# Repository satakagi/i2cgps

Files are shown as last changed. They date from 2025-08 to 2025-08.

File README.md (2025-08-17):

# I2CGPS

これは一般的なGPSレシーバ (GY-NEO6MV2など、UART 9600bpsでNMEA0183形式のデータを出力する。3.3Vでも動くもの) をI2Cインターフェースで使用できるようにするものです。メインコンピューターのUARTに余裕がないときに便利かもしれません。Arduino Pro Mini 3.3V (8MHz)でI2Cに変換しています。GY-NEO6MV2+Arduino Pro Mini 3.3V互換ボード+CHIRIMEN PiZero環境で動作確認をしました。

https://github.com/ckuethe/i2cgps をフォークして開発しました。そのため、i2cのインターフェース仕様はフォーク元に準じます。
ただ、私のArduino環境ではオリジナルのソース(.ino)はうまく動かなかったので、GPSライブラリの変更を伴う作り直しをしています。

原作者さんはATTiny85への移行を目指したようですが未達、この実装もArduino(ATMega248)用です。

また、以下を追加しています。
* [chirimen](https://www.chirimen.org)用のドライバとサンプル：[chirimen](./chirimen/)ディレクトリ
* 実体配線図：[hardware](./hardware)
* 未検証ですが・・KiCadのプリント基板設計図：[hardware/KiCad/](./hardware/KiCad/)

## 準備するもの
* GPSレシーバ([GY-NEO6MV2](https://electronicwork.shop/items/625c1ca99fe3d707d725cbe1)で確認しています)
* Arduiono Pro Mini 3.3V (8MHz) （もしくはその互換ボード）：この配線図通りで動かすには3.3V版が必要です ([互換ボードは数百円](https://electronicwork.shop/items/64e2182be37f74003b45e342)で購入できると思います)
* Arduiono Pro Miniにファームウェア(スケッチ)を書き込むための環境(ハードとしてはFTDI USBシリアル変換アダプター([数百円](https://electronicwork.shop/items/63412a95c15c5a192180482f)で買えると思います)が必要です)
* [Chirimen Pi Zero 環境](https://tutorial.chirimen.org/pizero/)

## 動かし方
* ファームウェアの書き込み：Arduino Pro Mini 3.3V(もしくはその互換ボード)にUSB-シリアル(専用のものが安価に流通しています)に、ArduinoIDEで[i2cgps.ino](./i2cgps.ino)を書き込みます
* 実体配線図のようにつなぎます
* GPSレシーバが測位できていなくても、空のデータが送信されてくるため、Arduino側のLEDは点滅するはずです（点滅していないときはどこかに問題がある）
* 測位できるとGPSレシーバ側のLEDも点滅します(GY-NEO6MV2の場合)
* chirimen piZero環境で[サンプルコード(ドライバ付き)](./chirimen/main.js)を実行すると、データが出力されます

## 実体配線図
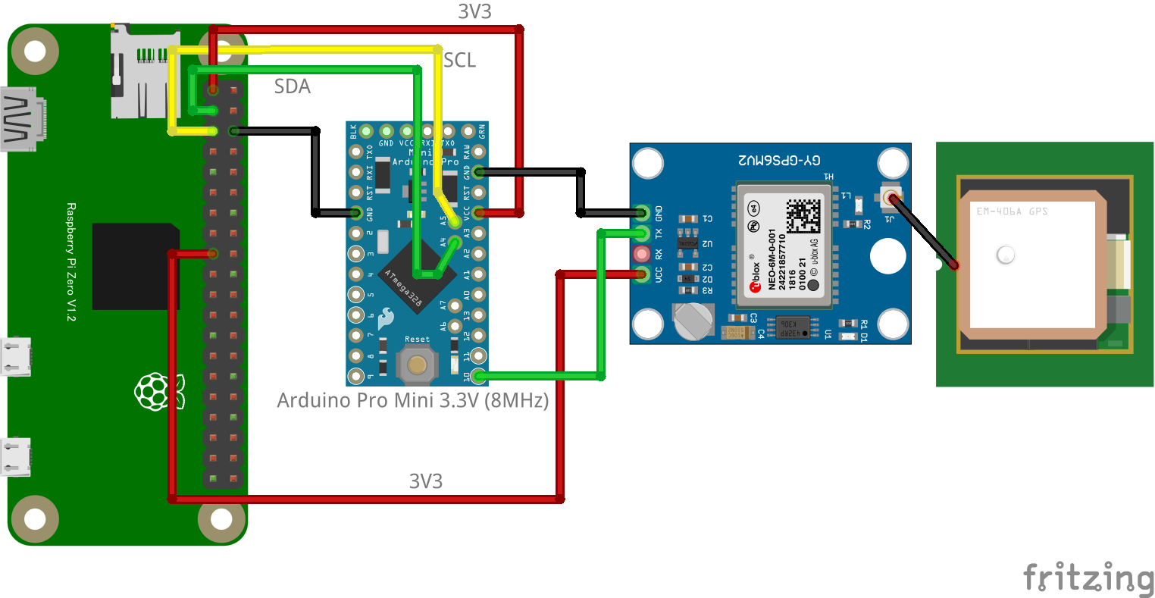
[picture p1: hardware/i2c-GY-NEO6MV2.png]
実体配線図


## ライセンス
ライセンスは原作者さんが明示していないので・・・　[The TAPR Open Hardware License](https://tapr.org/the-tapr-open-hardware-license/)を提示しておきます。

---

## 以下は原作者 (ckuetheさん)の作成されたREADMEです。

From time to time you want to attach a GPS to a microcontroller and
you're already using all the serial ports. Luckily we have another bus:
I2C. You could call it a kind of a controller-area-network, given that
there are master and slave devices, each of which has a unique address.

Unfortunately there are very few commercial
[I2C GPS](https://www.sparkfun.com/products/14414) receivers and they
just do NMEA over I2C. There are
[other projects](http://www.technoblogy.com/show?1LJI) that do something similar, but with a higher part count. 

This particular implementation rather wastefully uses an ATmega, eg. an
Arduino Nano.

### TODO

* port this to attiny85, eg. digispark

### Other Links

* https://playground.arduino.cc/Code/USIi2c/
* https://github.com/rambo/TinyWire/tree/master/TinyWireS
* https://github.com/lucullusTheOnly/TinyWire
* https://github.com/adafruit/TinyWireM
* https://github.com/harbaum/I2C-Tiny-USB/tree/master/digispark
* https://digistump.com/board/index.php?topic=2831.0
* https://digistump.com/board/index.php?topic=1147.0
* https://digistump.com/wiki/digispark/tutorials/lcd

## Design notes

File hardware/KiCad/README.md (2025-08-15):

# I2CGPS専用基板
KiCadで専用基板をデザインしてみました。が、この基板は原案のみで製作していませんので未検証です。

## 回路図
Arduino Pro Miniをベースにしています
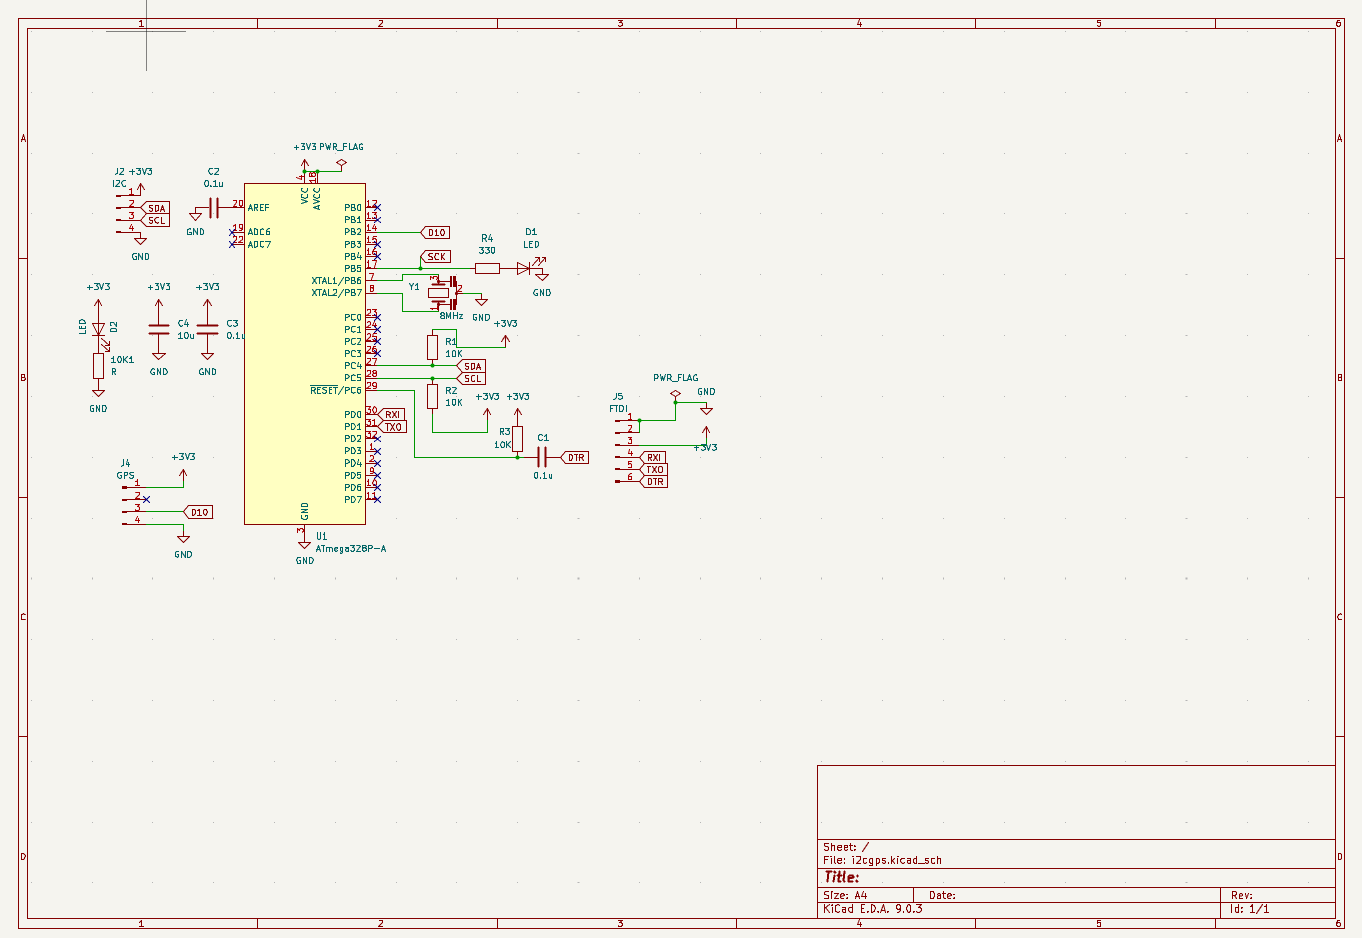
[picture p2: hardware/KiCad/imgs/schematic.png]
回路図


## PCBイメージ
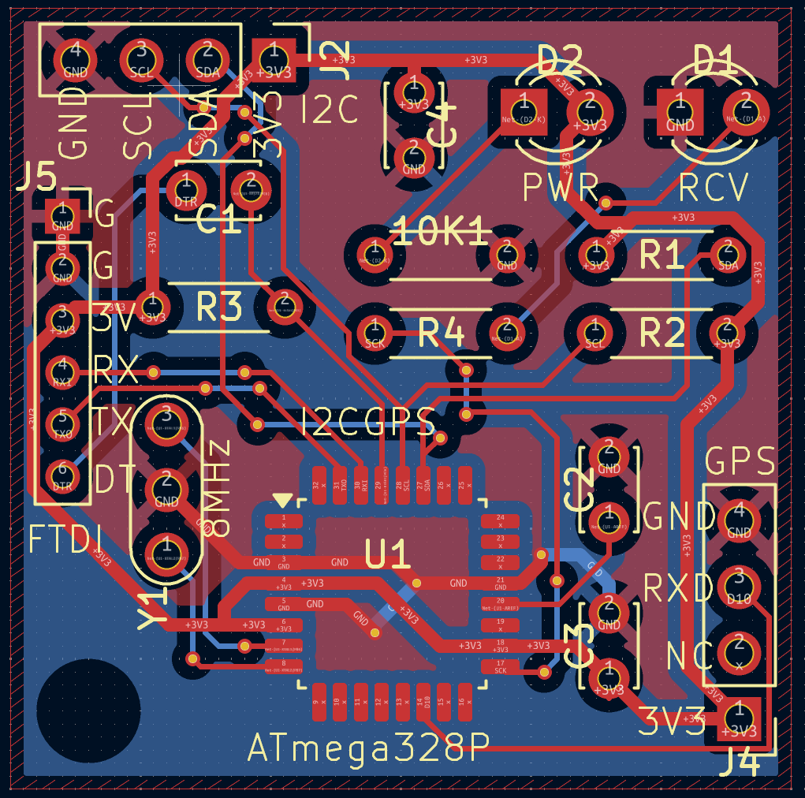
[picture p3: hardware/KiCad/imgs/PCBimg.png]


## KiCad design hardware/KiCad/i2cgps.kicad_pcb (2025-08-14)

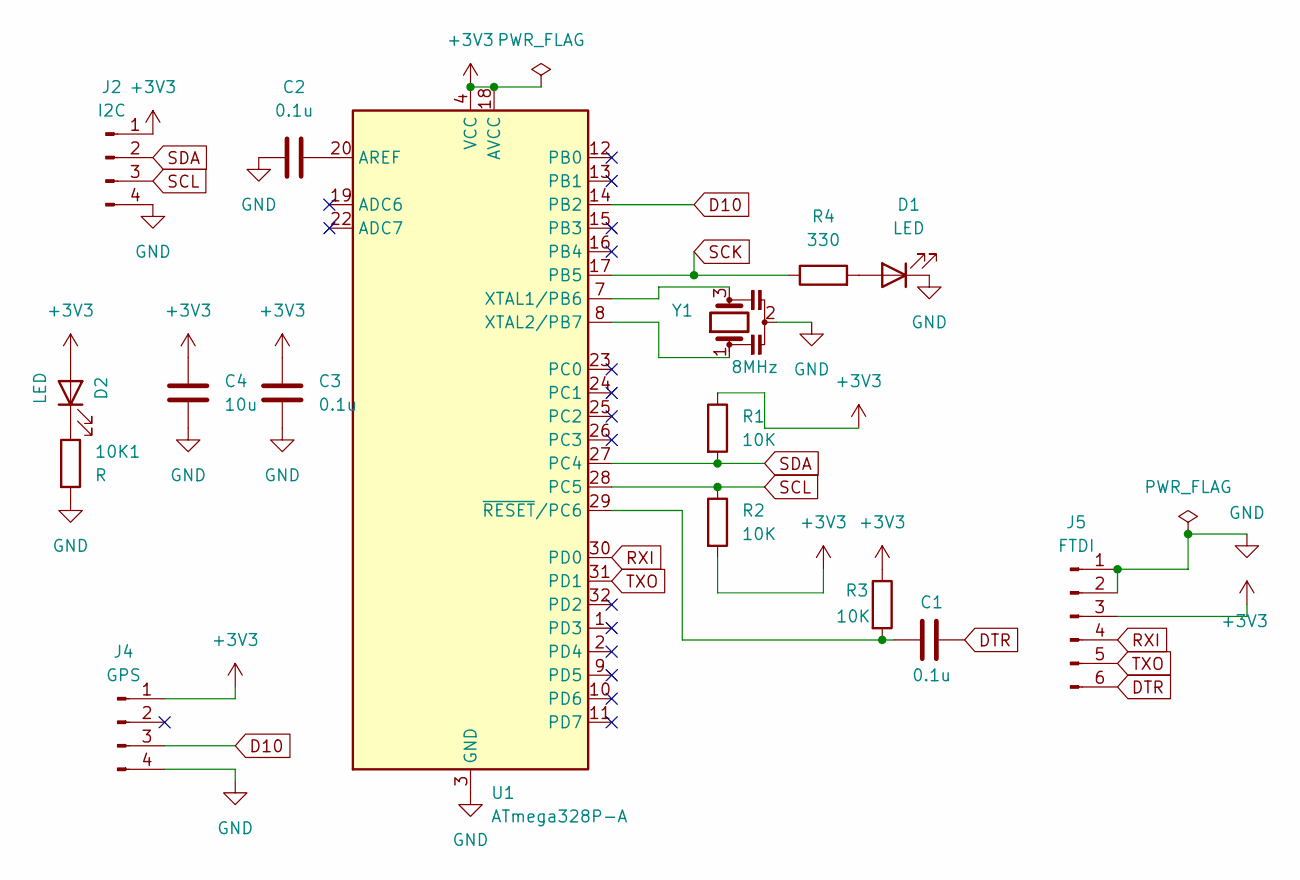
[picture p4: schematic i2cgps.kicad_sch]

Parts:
10K1: R; R_Axial_DIN0204_L3.6mm_D1.6mm_P5.08mm_Horizontal
C1, C2, C3: 0.1u; C_Disc_D3.0mm_W2.0mm_P2.50mm
C4: 10u; C_Disc_D3.0mm_W2.0mm_P2.50mm
D1, D2: LED; LED_D3.0mm
J2: I2C; PinHeader_1x04_P2.54mm_Vertical
J4: GPS; PinHeader_1x04_P2.54mm_Vertical
J5: FTDI; PinSocket_1x06_P2.00mm_Vertical
R1, R2, R3: 10K; R_Axial_DIN0204_L3.6mm_D1.6mm_P5.08mm_Horizontal
R4: 330; R_Axial_DIN0204_L3.6mm_D1.6mm_P5.08mm_Horizontal
U1: ATmega328P-A; TQFP-32_7x7mm_P0.8mm
Y1: 8MHz; Resonator_Murata_DSN6-3Pin_W7.0mm_H2.5mm

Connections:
+3V3: C3.1, C4.1, D2.2 (A), J2.1, J4.1, J5.3, R1.1, R2.2, R3.1, U1.4 (VCC), U1.6 (VCC), U1.18 (AVCC)
D10: J4.3, U1.14 (PB2)
DTR: C1.1, J5.6
GND: 10K1.2, C2.2, C3.2, C4.2, D1.1 (K), J2.4, J4.4, J5.1, J5.2, U1.3 (GND), U1.5 (GND), U1.21 (GND), Y1.2
unnamed: D1.2 (A), R4.2
unnamed: 10K1.1, D2.1 (K)
unnamed: C2.1, U1.20 (AREF)
unnamed: U1.7 (XTAL1/PB6), Y1.3
unnamed: U1.8 (XTAL2/PB7), Y1.1
unnamed: C1.2, R3.2, U1.29 (~RESET/PC6)
RXI: J5.4, U1.30 (PD0)
SCK: R4.1, U1.17 (PB5)
SCL: J2.3, R2.1, U1.28 (PC5)
SDA: J2.2, R1.2, U1.27 (PC4)
TXO: J5.5, U1.31 (PD1)

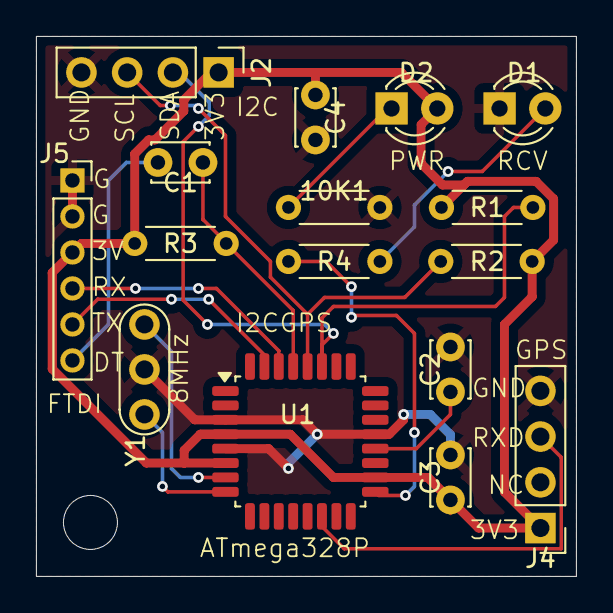
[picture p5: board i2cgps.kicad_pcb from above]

Board: 2 copper layers, 30.0 x 30.0 mm, 16 parts (0 on the bottom side), 15 nets.

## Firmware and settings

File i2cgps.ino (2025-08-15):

/*
 * Yet Another I2C GPS firmware with TinyGPSPlus
 *
 * TinyGPSPlusライブラリを使用してGPSデータを解析し、
 * I2C経由でデータを送信するファームウェアです。
 * NeoSWSerialでソフトウェアシリアル通信を行います。
 *
 * 【変更点】
 * ・使用ライブラリをNeoGPSからTinyGPSPlusに変更。(日付がおかしかった)
 * ・ライブラリのバージョン互換性のため、基本的な機能に絞って実装。
 * ・I2C送信時の緯度・経度データの計算方法を修正し、精度を向上。
 */

#include <Wire.h>
#include <WireData.h>
#include <NeoSWSerial.h>
#include <TinyGPSPlus.h> // TinyGPSPlusライブラリをインクルード

// GPSモジュールのボーレート
const long GPS_BAUD_RATE = 9600;

// PCのシリアルモニターのボーレート
const long PC_BAUD_RATE = 57600;

// I2Cアドレス
const int i2c_addr = 0x58;

// GPSモジュールのRXピンとTXピンを設定
NeoSWSerial gpsPort(10, 19); 

// TinyGPSPlusオブジェクトの宣言
TinyGPSPlus gps;

// I2Cで送信するデータ構造体
typedef struct fix {
  uint8_t fixlen;
  uint8_t status;
  uint16_t year;
  uint8_t month, day, hour, minute, second;
  int32_t lat, lon;
  int32_t alt;
  uint32_t speed;
} Fix_t;

// 送信するデータ構造体
static Fix_t i2c_fix;

// I2Cリクエストハンドラ
void i2c_position_request() {
  i2c_fix.fixlen = sizeof(i2c_fix);
  
  // TinyGPSPlusのデータで構造体を埋める
  i2c_fix.status = (uint8_t)gps.location.isValid(); // isValid()を使用
  
  // 緯度・経度データをrawLat/rawLngのdegとbillionthsから計算
  // 10^-7の単位で整数として送信
  RawDegrees latRaw = gps.location.rawLat();
  RawDegrees lngRaw = gps.location.rawLng();
  i2c_fix.lat = latRaw.deg * 10000000L + latRaw.billionths / 100L;
  i2c_fix.lon = lngRaw.deg * 10000000L + lngRaw.billionths / 100L;
  if (latRaw.negative) i2c_fix.lat = -i2c_fix.lat;
  if (lngRaw.negative) i2c_fix.lon = -i2c_fix.lon;

  i2c_fix.alt = gps.altitude.meters() * 100; // 高度をメートルからセンチメートルに変換
  i2c_fix.speed = gps.speed.kmph() * 10; // km/hの10倍として速度を取得

  // TinyGPSPlusから日時情報を取得
  i2c_fix.year = gps.date.year();
  i2c_fix.month = gps.date.month();
  i2c_fix.day = gps.date.day();
  i2c_fix.hour = gps.time.hour();
  i2c_fix.minute = gps.time.minute();
  i2c_fix.second = gps.time.second();
  
  // I2C経由で構造体を送信
  wireWriteData(i2c_fix);
}


void setup() {
  Serial.begin(PC_BAUD_RATE);
  Serial.println("Arduino Pro Mini has started.");
  Serial.println("Waiting for GPS data...");
  
  gpsPort.begin(GPS_BAUD_RATE);
  
  i2c_fix.fixlen = sizeof(i2c_fix);
  Wire.begin(i2c_addr);
  Wire.onRequest(i2c_position_request);
  
  pinMode(LED_BUILTIN, OUTPUT);
}


void loop() {
  // GPSポートにデータが届いていれば、
  // TinyGPSPlusでデータを解析する
  while (gpsPort.available()) {
    gps.encode(gpsPort.read());
  }
  
  // 新しいfixが取得できたら、シリアル出力
  if (gps.location.isUpdated()) {
    digitalWrite(LED_BUILTIN, !digitalRead(LED_BUILTIN));
    
    Serial.println("--------------------");
    Serial.print("Status: ");
    Serial.println(gps.location.isValid()); // isValid()を出力
    Serial.print("Latitude: ");
    Serial.println(gps.location.lat(), 7);
    Serial.print("Longitude: ");
    Serial.println(gps.location.lng(), 7);
    Serial.print("Date: ");
    Serial.print(gps.date.year());
    Serial.print("/");
    Serial.print(gps.date.month());
    Serial.print("/");
    Serial.print(gps.date.day());
    Serial.print(" ");
    Serial.print(gps.time.hour());
    Serial.print(":");
    Serial.print(gps.time.minute());
    Serial.print(":");
    Serial.println(gps.time.second());
    
    // DOP情報をシリアル出力に追加
    Serial.print("HDOP: ");
    Serial.println(gps.hdop.value() / 100.0, 2);
    
    Serial.println("--------------------");
  }
}

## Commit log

2025-08-14 Add schematics
    [i2c-GY-NEO6MV2.fzz, i2cgps.kicad_pcb, i2cgps.kicad_sch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]
2025-08-15 renamed: hardware/kiCad/imgs/PDBimg.png -> hardware/kiCad/imgs/PCBimg.png
